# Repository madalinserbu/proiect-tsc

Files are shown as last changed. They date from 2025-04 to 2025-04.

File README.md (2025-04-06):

# OpenBook
Proiect TSC - Serbu Ovidiu Madalin

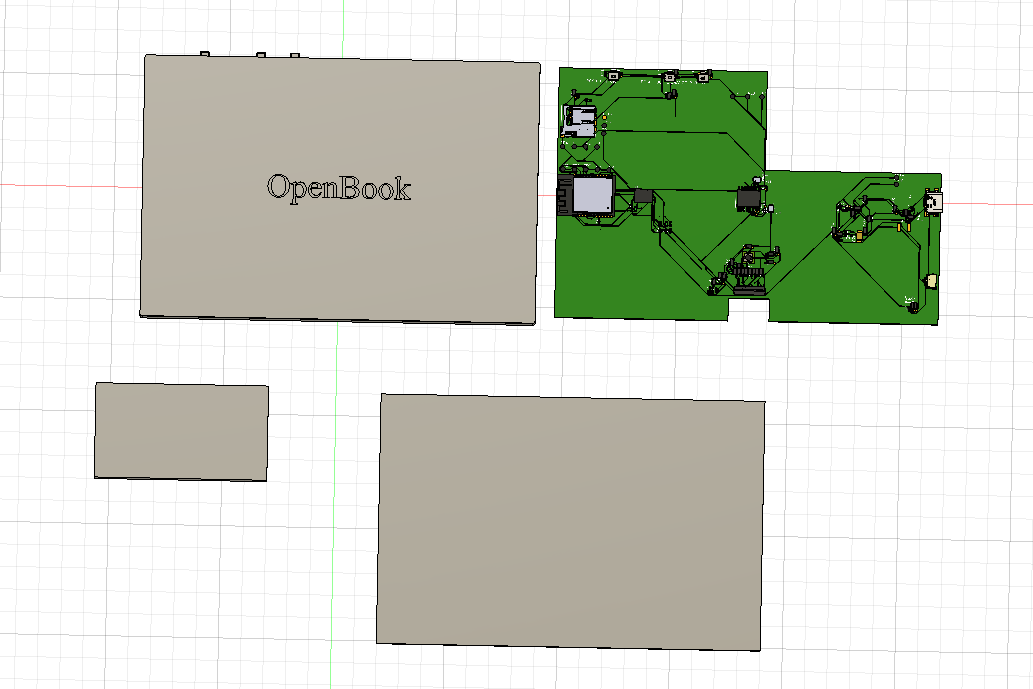
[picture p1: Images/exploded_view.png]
Exploded View


## Block Diagram

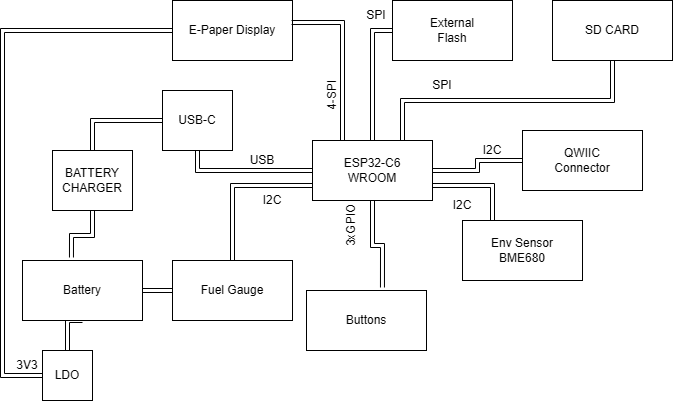
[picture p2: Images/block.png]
block


## Components

- **Microcontroller:** ESP32-C6 with integrated Wi-Fi 6 and Bluetooth 5 — responsible for core processing, communication, and power management.
- **Display:** 800×480 resolution e-Paper (e-Ink) display interfaced via SPI — ideal for low-power, high-visibility content rendering.
- **Sensors:** BME688 environmental sensor (temperature, humidity, pressure, air quality) connected through I2C.
- **Power Supply:** 2500mAh LiPo battery with USB-C charging and integrated fuel gauge for real-time battery monitoring.
- **Storage:** MicroSD card slot for storing e-books and other resources, communicating via SPI.
- **Real-Time Clock:** DS3231 RTC module with battery backup for accurate timekeeping even during power loss.
- **User Inputs:** 3 buttons (connected via GPIO) for navigation and control.
- **Expansion Options:** QWIIC/Stemma QT connector for easy integration of additional sensors or modules.

## Bill Of Materials

| name 	| value 	| description 	| quantity 	| link 	| datasheet 	|
|:---:	|:---:	|---	|:---:	|:---:	|---	|
| LED1 	| - 	| LED 	| 1 	| [link](https://www.niden.ro/led-uri-smd/4560-led-smd-0603-alb-rece.html) 	| [link](https://www.mouser.com/datasheet/2/423/LSM0603472V_(1)-1379786.pdf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)	|
| C18 	| 0.1uF/50V 	| CAPACITOR, European symbol 	| 1 	| [link](https://ro.mouser.com/ProductDetail/KEMET/C0402C104K4RAC7411?qs=GedzDrHbfJPMv36lRRfk4g%3D%3D) 	| [link](https://ro.mouser.com/datasheet/2/447/KEM_C1002_X7R_SMD-3316098.pdf) 	|
| R5 	| 0.47 	| RESISTOR, European symbol 	| 1 	| [link](https://ro.mouser.com/ProductDetail/ROHM-Semiconductor/SFR01MZPJ471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) 	| [link](https://fscdn.rohm.com/en/products/databook/datasheet/passive/resistor/chip_resistor/sfr-e.pdf) 	|
| R1 	| 100K 	| RESISTOR, European symbol 	| 1 	| [link](https://ro.mouser.com/ProductDetail/Bourns/CR0402-FX-1003GLF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) 	| [link](https://ro.mouser.com/datasheet/2/54/cr-1858361.pdf) 	|
| C1, C5, C21, C22, C23, C25, C26, C27 	| 100nF 	| CAPACITOR, European symbol 	| 8 	| [link](https://ro.mouser.com/ProductDetail/KEMET/C0402C104K4RAC7411?qs=GedzDrHbfJPMv36lRRfk4g%3D%3D) 	| [link](https://ro.mouser.com/datasheet/2/447/KEM_C1002_X7R_SMD-3316098.pdf) 	|
| C2 	| 100uF 	| POLARIZED CAPACITOR, European symbol 	| 1 	| [link](https://ro.mouser.com/ProductDetail/KEMET/T491B107M006AT?qs=U312oeP%2FpiHOgyk6KO2m0g%3D%3D) 	| [link](https://ro.mouser.com/datasheet/2/447/KEM_T2005_T491-3316937.pdf) 	|
| R18 	| 10K 	| RESISTOR, European symbol 	| 1 	| [link](https://ro.mouser.com/ProductDetail/Vishay-Dale/CRCW040210K0FKEDC?qs=E3Y5ESvWgWPiNLcGzwCGPg%3D%3D) 	| [link](https://www.vishay.com/docs/28773/crcwce3.pdf) 	|
| R6, R10, R11, R12, R13, R14, R15, R16, R19, R20, R21, R22, R23, R24, R25 	| 10k 	| RESISTOR, European symbol 	| 15 	| [link](https://ro.mouser.com/ProductDetail/Vishay-Dale/CRCW040210K0FKEDC?qs=E3Y5ESvWgWPiNLcGzwCGPg%3D%3D) 	| [link](https://www.vishay.com/docs/28773/crcwce3.pdf) 	|
| C7 	| 10uF 	| CAPACITOR, European symbol 	| 1 	| [link](https://ro.mouser.com/ProductDetail/KEMET/C0402C106M7PAC7867?qs=kZJHmUDErizJnkDIcqVWRQ%3D%3D) 	| [link](https://ro.mouser.com/datasheet/2/447/KEM_C1006_X5R_SMD-3316465.pdf) 	|
| J1 	| - 	| Micro SD Card Socket, Push-Push Type, Top Mount, SMT, H=1.83mm, 10u 	| 1 	| [link](https://www.digikey.ro/en/products/detail/attend-technology/112A-TAAR-R03/17633923) 	| [link](https://www.attend.com.tw/data/download/file/112A-TAAR-R03_Spec.pdf) 	|
| R17 	| 15 	| RESISTOR, European symbol 	| 1 	| [link](https://www.soselectronic.com/ro-ro/products/yageo/r0402-5-15-r-rc0402jr-0715rl-1-81614) 	| [link](https://cdn.soselectronic.com/productdata/4b/af/65353ac1/r0402-1-1-5-k-rc0402fr-071k5l-1.pdf) 	|
| C24 	| 1uF 	| CAPACITOR, European symbol 	| 1 	| [link](https://ro.mouser.com/ProductDetail/KEMET/C0402C105Z9VACTU?qs=gt1LBUVyoHlQieoJt4iw1w%3D%3D) 	| [link](https://ro.mouser.com/datasheet/2/447/KEM_C1005_Y5V_SMD-3316374.pdf) 	|
| C11, C12, C13, C14, C15, C16, C17, C19, C20 	| 1uF/50V 	| CAPACITOR, European symbol 	| 9 	| [link](https://ro.mouser.com/ProductDetail/KEMET/C0402C105Z9VACTU?qs=gt1LBUVyoHlQieoJt4iw1w%3D%3D) 	| [link](https://ro.mouser.com/datasheet/2/447/KEM_C1005_Y5V_SMD-3316374.pdf) 	|
| R7 	| 2.2 	| RESISTOR, European symbol 	| 1 	| [link](https://ro.mouser.com/ProductDetail/Panasonic/ERJ-PA2J2R2X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) 	| [link](https://industrial.panasonic.com/cdbs/www-data/pdf/RDO0000/AOA0000C331.pdf) 	|
| R8 	| 200 	| RESISTOR, European symbol 	| 1 	| [link](https://ro.mouser.com/ProductDetail/Vishay-Thin-Film/PNM0402E2000BSTS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) 	| [link](https://www.vishay.com/docs/60057/pnm.pdf) 	|
| Q1, Q3 	| 20V/4.2A/52mO/1.4W 	| P-channel MOSFETs 	| 2 	| [link](https://www.digikey.ro/en/products/detail/vishay-siliconix/SI1308EDL-T1-GE3/4876435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) 	| [link](https://www.vishay.com/docs/63399/si1308edl.pdf) 	|
| R9 	| 2k 	| RESISTOR, European symbol 	| 1 	| [link](https://ro.mouser.com/ProductDetail/Vishay-Dale/CRCW04022K00FKEE?qs=raETa%252B32nO8lGcRW9MjUBA%3D%3D) 	| [link](https://www.vishay.com/docs/20035/dcrcwe3.pdf) 	|
| C6, C9, C10 	| 4.7uF 	| CAPACITOR, European symbol 	| 3 	| [link](https://ro.mouser.com/ProductDetail/KEMET/C0402C475K8PACTU?qs=ulEaXIWI0c9ebKRT3r3htg%3D%3D) 	| [link](https://ro.mouser.com/datasheet/2/447/KEM_C1006_X5R_SMD-3316465.pdf) 	|
| C3, C4 	| 4.7uF 	| CAPACITOR, European symbol 	| 2 	| [link](https://ro.mouser.com/ProductDetail/KEMET/C0402C475K8PACTU?qs=ulEaXIWI0c9ebKRT3r3htg%3D%3D) 	| [link](https://ro.mouser.com/datasheet/2/447/KEM_C1006_X5R_SMD-3316465.pdf) 	|
| C8 	| 4.7uF/25V 	| CAPACITOR, European symbol 	| 1 	| [link](https://ro.mouser.com/ProductDetail/KEMET/C0402C475K8PACTU?qs=ulEaXIWI0c9ebKRT3r3htg%3D%3D) 	| [link](https://ro.mouser.com/ProductDetail/KEMET/C0402C475K8PACTU?qs=ulEaXIWI0c9ebKRT3r3htg%3D%3D) 	|
| D3 	| 4.7uF/25V 	| ON SEMICONDUCTOR - MBR0530 - DIODE, SCHOTTKY, 0.5A, 30V, SOD-123 	| 1 	| [link](https://www.snapeda.com/parts/MBR0530/Onsemi/view-part/?ref=eda) 	| [link](https://www.snapeda.com/parts/MBR0530/ON%20Semiconductor/datasheet/) 	|
| R3, R4 	| 5k1 	| RESISTOR, European symbol 	| 2 	| [link](https://www.gme.cz/v/1484336/yageo-r0402-5k1-006w-1-smd-rezistor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) 	| [link](https://img.gme.cz/files/eshop_data/eshop_data/7/984-017/dsh.984-017.1.pdf) 	|
| L1 	| 68uH 	| coil 	| 1 	| [link](https://ro.mouser.com/ProductDetail/Wurth-Elektronik/744043680?qs=PGXP4M47uW6VkZq%252BkzjrHA%3D%3D) 	| [link](https://www.we-online.com/components/products/datasheet/744043680.pdf) 	|
| IC2 	| - 	| Voltage Detector with Adjustable Delay 	| 1 	| [link](https://ro.mouser.com/ProductDetail/ROHM-Semiconductor/BD5229G-TR?qs=4kLU8WoGk0vvnhrrYwdszw%3D%3D) 	| [link](https://fscdn.rohm.com/en/products/databook/datasheet/ic/power/voltage_detector/bd52xxg-e.pdf) 	|
| BOOT_BUTTON, CHANGE_BUTTON, RESET_BUTTON 	| - 	| Button 	| 3 	| [link](https://ro.mouser.com/ProductDetail/CK/PTS841-GK-SMTR-LFS?qs=d0WKAl%252BL4KbAtAqJT9yhkg%3D%3D) 	| [link](https://www.ckswitches.com/media/2805/pts841.pdf) 	|
| C28 	| - 	| Cap 0.011F 3.3V 1210 Flat 	| 1 	| [link](https://www.snapeda.com/parts/CPH3225A/Seiko+Instruments/view-part/?ref=eda) 	| [link](https://www.snapeda.com/parts/CPH3225A/Seiko%20Instruments/datasheet/) 	|
| U5 	| - 	| Real Time Clock Serial 16-Pin SOIC W T/R 	| 1 	| [link](https://www.snapeda.com/parts/DS3231SN%23/Analog+Devices/view-part/?ref=eda) 	| [link](https://www.snapeda.com/parts/DS3231SN%23/Analog%20Devices/datasheet/) 	|
| U2 	| - 	| ESP32 	| 1 	| [link](https://www.snapeda.com/parts/ESP32-C6-WROOM-1-N8/Espressif+Systems/view-part/?ref=eda) 	| [link](https://www.snapeda.com/parts/ESP32-C6-WROOM-1-N8/Espressif%20Systems/datasheet/) 	|
| R2 	| - 	| VARISTOR 	| 1 	| [link](https://www.digikey.ro/en/products/detail/epcos-tdk-electronics/B72580T0110K062/15903564) 	| [link](https://www.tdk-electronics.tdk.com/inf/75/db/CTVS_14/Standard_series.pdf) 	|
| D1, D6 	| - 	| Schottky Barrier Rectifier Diode 	| 2 	| [link](https://eu.mouser.com/ProductDetail/KYOCERA-AVX/SD0805S020S1R0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) 	| [link](https://ro.mouser.com/datasheet/2/40/schottky-3165252.pdf) 	|
| U3 	| - 	| Integrated Environmental Unit 	| 1 	| [link](https://ro.mouser.com/ProductDetail/Bosch-Sensortec/BME680?qs=v271MhAjFHjo0yA%2FC4OnDQ%3D%3D) 	| [link](https://ro.mouser.com/datasheet/2/783/BST_BME680_DS001-1509608.pdf) 	|
| U1 	| - 	| MCP73831T Li-Ion, Li-Pol Controller 	| 1 	| [link](https://eu.mouser.com/ProductDetail/Microchip-Technology/MCP73831T-2ACI-OT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) 	| [link](https://ro.mouser.com/datasheet/2/268/MCP73831_Family_Data_Sheet_DS20001984H-3441711.pdf) 	|
| J3 	| - 	|  (0.50mm) Surface Mount, Right Angle 	| 1 	| [link](https://ro.mouser.com/ProductDetail/Hirose-Connector/FH34SRJ-24S-0.5SH99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.) 	| [link](https://ro.mouser.com/datasheet/2/185/FH34SRJ_24S_0_5SH_99__CL0580_1255_6_99_2DDrawing_0-1615044.pdf) 	|
| U4 	| - 	| 3µA 1-Cell/2-Cell Fuel Gauge with ModelGauge 	| 1 	| [link](https://www.snapeda.com/parts/MAX17048G+T10/Analog+Devices/view-part/?ref=eda) 	| [link](https://www.snapeda.com/parts/MAX17048G+T10/Analog%20Devices/datasheet/) 	|
| D4, D5 	| - 	| DIODE, SCHOTTKY, 0.5A, 30V, SOD-123 	| 2 	| [link](https://www.snapeda.com/parts/MBR0530/Onsemi/view-part/?ref=eda) 	| [link](https://www.snapeda.com/parts/MBR0530/ON%20Semiconductor/datasheet/) 	|
| D7, D8, D9, D10, D11, D12 	| - 	| Ipp Tvs Diode 	| 6 	| [link](https://www.snapeda.com/parts/PGB1010603MR/Littelfuse/view-part/?ref=eda) 	| [link](https://www.snapeda.com/parts/PGB1010603MR/Littelfuse%20Inc./datasheet/) 	|
| J4 	| - 	| SparkFun I2C Standard Qwiic Connector 	| 1 	| [link](https://www.sparkfun.com/qwiic-jst-connector-smd-4-pin-horizontal.html) 	| [link](https://cdn.sparkfun.com/assets/parts/1/2/2/8/9/Qwiic_Connector_Datasheet.pdf) 	|
| J2 	| - 	| CONN USB 2.0 TYPE-C R/A SMT 	| 1 	| [link](https://ro.mouser.com/ProductDetail/GCT/USB4110-GF-A?qs=KUoIvG%2F9IlYiZvIXQjyJeA%3D%3D) 	| [link](https://ro.mouser.com/datasheet/2/837/GCT_USB4110_Product_Drawing___20k_cycles-3455479.pdf) 	|
| Q2 	| - 	| MOSFET N-Ch 30V 1.5A 	| 1 	| [link](https://www.snapeda.com/parts/SI1308EDL-T1-GE3/Vishay+Siliconix/view-part/?ref=eda) 	| [link](https://www.snapeda.com/parts/SI1308EDL-T1-GE3/Vishay%20Siliconix/datasheet/) 	|
| D2 	| - 	| Low Cap. ESD Protection Auto SOT-23-6 	| 1 	| [link](https://www.snapeda.com/parts/USBLC6-2SC6Y/STMicroelectronics/view-part/?ref=eda) 	| [link](https://www.snapeda.com/parts/USBLC6-2SC6Y/STMicroelectronics/datasheet/) 	|
| U6 	| - 	| FLASH - NOR Memory IC 512Mb 	| 1 	| [link](https://www.snapeda.com/parts/W25Q512JVEIQ/Winbond+Electronics/view-part/?ref=eda) 	| [link](https://www.snapeda.com/parts/W25Q512JVEIQ/Winbond%20Electronics/datasheet/) 	|
| IC1 	| - 	| LDO Voltage Regulator 	| 1 	| [link](https://ro.mouser.com/ProductDetail/Torex-Semiconductor/XC6220A331MR-G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) 	| [link](https://ro.mouser.com/datasheet/2/760/xc6220-3371556.pdf) 	|

## ESP32-C6 Pins

| Connection | Pin | Description |
|---|---|---|
| **RESET** | EN | Reset button for initiating a reset sequence |
| **INT_RTC** | IO0 | Interrupt signal for the RTC |
| **32KHZ** | IO1 | Input for 32kHz clock signal |
| **MISO** | IO2 | Master In Slave Out for communication between the microcontroller, Flash, SD Card, and display |
| **EPD_BUSY** | IO3 | Signal indicating if the display is busy |
| **SS_SD** | IO4 | Chip select for the SD card |
| **EPD_DC** | IO5 | Display data/command control pin |
| **SCK** | IO6 | SPI clock for synchronizing data transfers |
| **MOSI** | IO7 | Master Out Slave In for data transmission between the microcontroller, Flash, SD card, and display |
| **3V3** | IO8 | 3.3V power supply |
| **IO/BOOT** | IO9 | Boot button to trigger boot process |
| **EPD_CS** | IO10 | Chip select for the display |
| **FLASH_CS** | IO11 | Chip select for the Flash memory |
| **USB_D-** | IO12 | USB data negative for communication |
| **USB_D+** | IO13 | USB data positive for communication |
| **IO/CHANGE** | IO15 | Button to trigger a change action |
| **TX (UART)** | TXD0 / GPIO16  | Serial transmitter for UART communication |
| **RX (UART)** | RXD0 / GPIO17  | Serial receiver for UART communication |
| **RTC_RST** | IO18 | External reset for the RTC module |
| **I2C_PW** | IO19 | Power control signal for I2C devices |
| **EPD_3V3_C** | IO20 | 3.3V power supply for the display |
| **SDA (I2C)** | IO21 | Data line for I2C communication (e.g., RTC, BME688, Battery Gauge) |
| **SCL (I2C)** | IO22 | Clock line for I2C synchronization |
| **EPD_RST** | IO23 | Reset signal for the display |
| **3V3** | 3V3 | 3.3V power line |
| **GND** | GND | Ground connection |

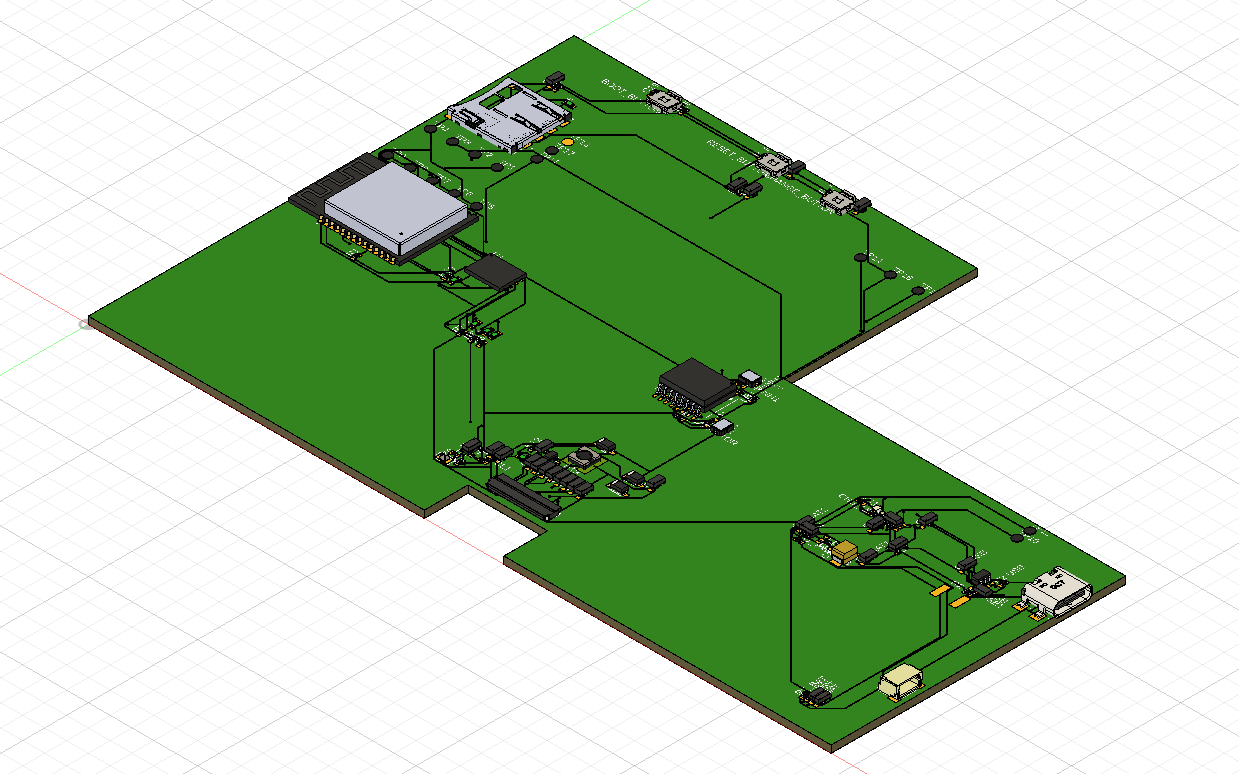
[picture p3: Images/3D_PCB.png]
3DPCB


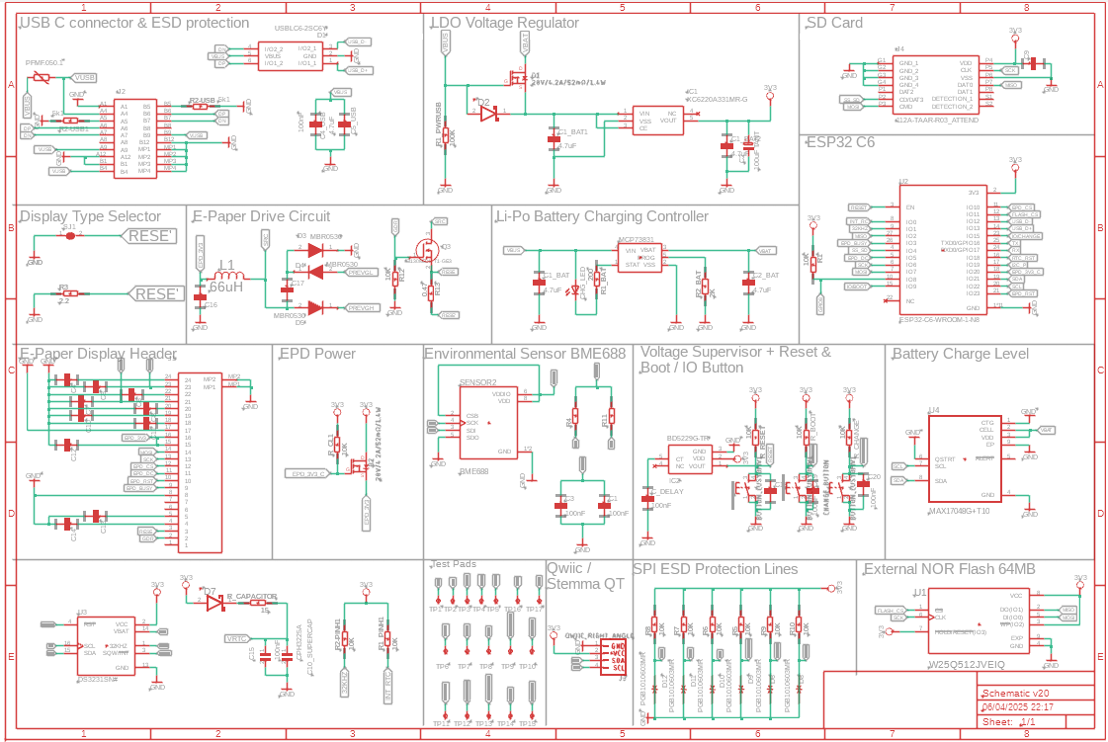
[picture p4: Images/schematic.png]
schematic


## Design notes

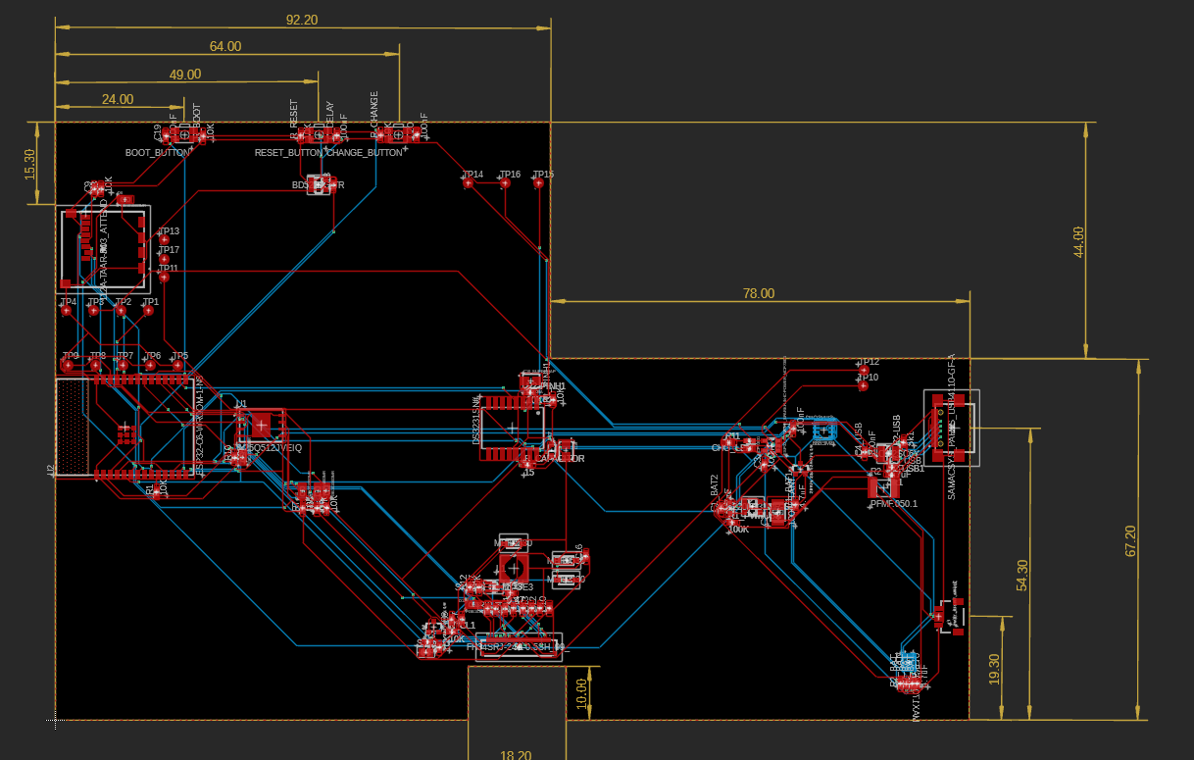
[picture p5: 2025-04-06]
Images/2D_PCB.png

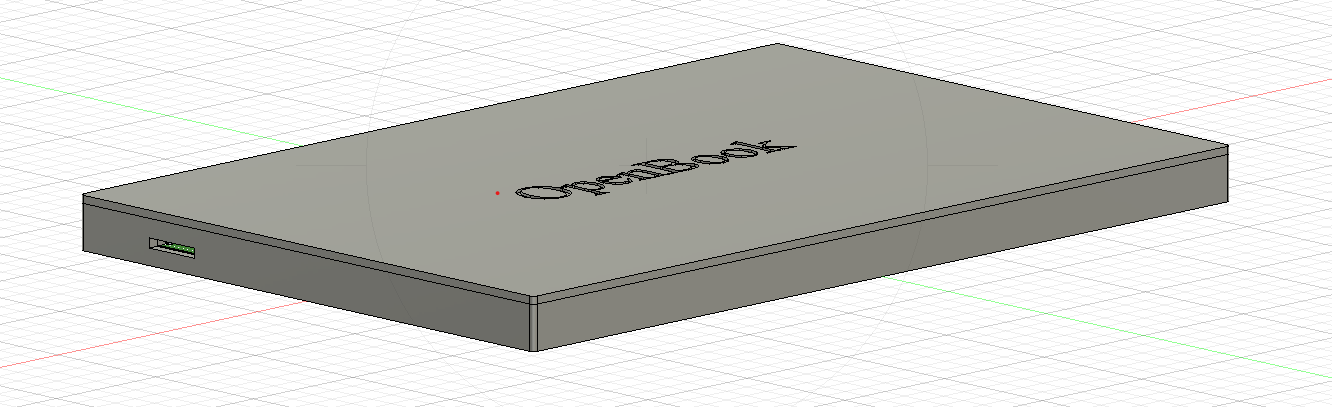
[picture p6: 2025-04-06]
Images/complete_device.png

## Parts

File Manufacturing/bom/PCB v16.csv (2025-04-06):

Qty | Value | Device | Package | Parts | Description | ARROW_PART_NUMBER | ARROW_PRICE-STOCK | AVAILABILITY | CENTROID_NOT_SPECIFIED | CHECK_PRICES | COPYRIGHT | DATASHEET | DESCRIPTION | DIGIKEY_DESCRIPTION | DIGIKEY_PART_NUMBER | HEIGHT | LEAD_FREE | MANUFACTURER_NAME | MANUFACTURER_PART_NUMBER | MF | MFR_NAME | MOUSER_PART_NUMBER | MOUSER_PRICE-STOCK | MOUSER_TESTING_PART_NUMBER | MOUSER_TESTING_PRICE-STOCK | MP | MPN | PACKAGE | POPULARITY | PREFIX | PRICE | PROD_ID | PURCHASE-URL | ROHS | SNAPEDA_LINK | SPICEMODEL | SPICEPREFIX | TEMPERATURE_RANGE_HIGH | TEMPERATURE_RANGE_LOW | TP_SIGNAL_NAME | VALUE
1 |  | ADAFRUIT_LEDCHIP-LED0603 | ADAFRUIT_CHIP-LED0603 | CHG_LED | LED
14 |  | ESP32_WROVER_EAGLE-LTSPICE_CC0402 | ESP32_WROVER_EAGLE-LTSPICE_C0402 | C4, C5, C6, C7, C8, C9, C10, C11, C12, C13, C14, C16, C17, C18 | CAPACITOR, European symbol |  |  |  |  |  |  |  |  |  |  |  |  |  |  |  |  |  |  |  |  |  |  |  |  |  |  |  |  |  |  | NONE | C
2 |  | ESP32_WROVER_EAGLE-LTSPICE_RR0402 | ESP32_WROVER_EAGLE-LTSPICE_R0402 | R4, R11 | RESISTOR, European symbol |  |  |  |  |  |  |  |  |  |  |  |  |  |  |  |  |  |  |  |  |  |  |  |  |  |  |  |  |  |  | NONE | R
1 |  | SJ | SJ | SJ1 | SMD solder JUMPER |  |  |  |  |  |  |  |  |  |  |  |  |  |  |  |  |  |  |  |  |  |  |  | 3
1 | 0.47 | ESP32_WROVER_EAGLE-LTSPICE_RR0402 | ESP32_WROVER_EAGLE-LTSPICE_R0402 | R13 | RESISTOR, European symbol |  |  |  |  |  |  |  |  |  |  |  |  |  |  |  |  |  |  |  |  |  |  |  |  |  |  |  |  |  |  | NONE | R
1 | 100K | ESP32_WROVER_EAGLE-LTSPICE_RR0402 | ESP32_WROVER_EAGLE-LTSPICE_R0402 | R1_PWRUSB | RESISTOR, European symbol |  |  |  |  |  |  |  |  |  |  |  |  |  |  |  |  |  |  |  |  |  |  |  |  |  |  |  |  |  |  | NONE | R
1 | 100nF | CPH3225A | CAPCP3225X100N | C15 | Cap 0.011F 3.3V 1210 Flat Check availability |  |  | Not in stock |  | https://www.snapeda.com/parts/CPH3225A/Seiko+Instruments/view-part/?ref=eda |  |  | 11 mF (EDLC) Supercapacitor 3.3 V 1210 (3225 Metric) - - |  |  |  |  |  |  | Seiko Instruments |  |  |  |  |  | CPH3225A |  | 1210 Seiko |  |  | None |  | https://www.snapeda.com/api/url_track_click_mouser/?unipart_id=562593&manufacturer=Seiko Instruments&part_name=CPH3225A&search_term=None |  | https://www.snapeda.com/parts/CPH3225A/Seiko+Instruments/view-part/?ref=snap
1 | 100nF | EAGLE-LTSPICE_CC0402 | ESP32_WROVER_EAGLE-LTSPICE_C0402 | C19 | CAPACITOR, European symbol |  |  |  |  |  |  |  |  |  |  |  |  |  |  |  |  |  |  |  |  |  |  |  |  |  |  |  |  |  |  | NONE | C
5 | 100nF | ESP32_WROVER_EAGLE-LTSPICE_CC0402 | ESP32_WROVER_EAGLE-LTSPICE_C0402 | C1, C3, C4_USB, C20, C_DELAY | CAPACITOR, European symbol |  |  |  |  |  |  |  |  |  |  |  |  |  |  |  |  |  |  |  |  |  |  |  |  |  |  |  |  |  |  | NONE | C
1 | 100uF TANT | RCL_CPOL-EUCT3528 | RCL_CT3528 | C2 | POLARIZED CAPACITOR, European symbol |  |  |  |  |  |  |  |  |  |  |  |  |  |  |  |  |  |  |  |  |  |  |  | 0 |  |  |  |  |  |  |  | C
14 | 10K | ESP32_WROVER_EAGLE-LTSPICE_RR0402 | ESP32_WROVER_EAGLE-LTSPICE_R0402 | R1, R1_PINH1, R2-PINH1, R5, R6, R7, R8, R9, R10, R12, R_BOOT, R_CHANGE, R_CL1, R_RESET | RESISTOR, European symbol |  |  |  |  |  |  |  |  |  |  |  |  |  |  |  |  |  |  |  |  |  |  |  |  |  |  |  |  |  |  | NONE | R
1 | 112A-TAAR-R03_ATTEND | 112A-TAAR-R03_ATTEND | 112ATAARR03ATTEND | J4 | Micro SD Card Socket, Push-Push Type, Top Mount, SMT, H=1.83mm, 10u |  |  |  |  |  |  |  | Micro SD Card Socket | Push-Push Type | Top Mount | SMT | H=1.83mm | 10u |  |  | 1.9mm |  | ATTEND | 112A-TAAR-R03 ATTEND
1 | 15 | ESP32_WROVER_EAGLE-LTSPICE_RR0402 | ESP32_WROVER_EAGLE-LTSPICE_R0402 | R_CAPACITOR | RESISTOR, European symbol |  |  |  |  |  |  |  |  |  |  |  |  |  |  |  |  |  |  |  |  |  |  |  |  |  |  |  |  |  |  | NONE | R
1 | 2.2 | ESP32_WROVER_EAGLE-LTSPICE_RR0402 | ESP32_WROVER_EAGLE-LTSPICE_R0402 | R3 | RESISTOR, European symbol |  |  |  |  |  |  |  |  |  |  |  |  |  |  |  |  |  |  |  |  |  |  |  |  |  |  |  |  |  |  | NONE | R
1 | 200 | ESP32_WROVER_EAGLE-LTSPICE_RR0402 | ESP32_WROVER_EAGLE-LTSPICE_R0402 | R1_BAT | RESISTOR, European symbol |  |  |  |  |  |  |  |  |  |  |  |  |  |  |  |  |  |  |  |  |  |  |  |  |  |  |  |  |  |  | NONE | R
2 | 20V/4.2A/52mO/1.4W | ESP32_WROVER_SPARKFUN-DISCRETESEMI_MOSFET_PCH-DMG2305UX-7 | ESP32_WROVER_SPARKFUN-DISCRETESEMI_SOT23-3 | Q1, Q2 | P-channel MOSFETs |  |  |  |  |  |  |  |  |  |  |  |  |  |  |  |  |  |  |  |  |  |  |  |  |  |  | TRAN-14388 |  |  |  |  |  |  |  |  | 20V/4.2A/52mO/1.4W
1 | 2K | ESP32_WROVER_EAGLE-LTSPICE_RR0402 | ESP32_WROVER_EAGLE-LTSPICE_R0402 | R2_BAT | RESISTOR, European symbol |  |  |  |  |  |  |  |  |  |  |  |  |  |  |  |  |  |  |  |  |  |  |  |  |  |  |  |  |  |  | NONE | R
5 | 4.7uF | ESP32_WROVER_EAGLE-LTSPICE_CC0402 | ESP32_WROVER_EAGLE-LTSPICE_C0402 | C1_BAT, C1_BAT1, C1_BAT2, C2_BAT, C5_USB | CAPACITOR, European symbol |  |  |  |  |  |  |  |  |  |  |  |  |  |  |  |  |  |  |  |  |  |  |  |  |  |  |  |  |  |  | NONE | C
2 | 5k1 | ESP32_WROVER_EAGLE-LTSPICE_RR0402 | ESP32_WROVER_EAGLE-LTSPICE_R0402 | R2-USB, R2-USB1 | RESISTOR, European symbol |  |  |  |  |  |  |  |  |  |  |  |  |  |  |  |  |  |  |  |  |  |  |  |  |  |  |  |  |  |  | NONE | R
1 | 66uH | 744043680IND_4828-WE-TPC_WRE | IND_4828-WE-TPC_WRE | L1 |  |  |  |  |  |  | Copyright (C) 2024 Ultra Librarian. All rights reserved. |  |  |  |  |  |  |  | 744043680 |  | Wurth Electronics
1 | BD5229G-TR | BD5229G-TR | SOT95P280X125-5N | IC2 | Voltage Detector with Adjustable Delay Time: CMOS processes are utilized to develop high precision, low current consumption CMOS reset ICs that allow arbitrary setting of the delay time. The extensive lineup includes both Nch Open Drain and CMOS output types in a wide range of detection voltages (from 2.3V to 6.0V, in 0.1V steps), enabling selection of the ideal solution based on customer requirements. In addition, the entire series is of course both lead-free and RoHS-compliant. |  |  |  |  |  |  |  | Voltage Detector with Adjustable Delay Time: CMOS processes are utilized to develop high precision | low current consumption CMOS reset ICs that allow arbitrary setting of the delay time. The extensive lineup includes both Nch Open Drain and CMOS output types in a wide range of detection voltages (from 2.3V to 6.0V | in 0.1V steps) | enabling selection of the ideal solution based on customer requirements. In addition | the entire series is of course both lead-free and RoHS-compliant. |  |  | 1.25mm |  | ROHM Semiconductor | BD5229G-TR |  |  | 755-BD5229G-TR | https://www.mouser.co.uk/ProductDetail/ROHM-Semiconductor/BD5229G-TR?qs=4kLU8WoGk0vvnhrrYwdszw%3D%3D
1 | BME688 | ESP32_WROVER_BME680_BME680 | ESP32_WROVER_BME680_PSON80P300X300X100-8N | SENSOR2 | Integrated Environmental Unit |  |  | Unavailable |  |  |  |  | Integrated Environmental Unit |  |  |  |  |  |  | Bosch Sensortec |  |  |  |  |  | BME680 |  | LGA-8 Bosch Tools |  |  | None
3 | BUTTON_CUSYOMV1 | BUTTON_CUSYOMV1 | MYBUTTON | BOOT_BUTTON, CHANGE_BUTTON, RESET_BUTTON
1 | CPH3225A | CPH3225A | CAPCP3225X100N | C10_SUPERCAP | Cap 0.011F 3.3V 1210 Flat Check availability |  |  | Not in stock |  | https://www.snapeda.com/parts/CPH3225A/Seiko+Instruments/view-part/?ref=eda |  |  | 11 mF (EDLC) Supercapacitor 3.3 V 1210 (3225 Metric) - - |  |  |  |  |  |  | Seiko Instruments |  |  |  |  |  | CPH3225A |  | 1210 Seiko |  |  | None |  | https://www.snapeda.com/api/url_track_click_mouser/?unipart_id=562593&manufacturer=Seiko Instruments&part_name=CPH3225A&search_term=None |  | https://www.snapeda.com/parts/CPH3225A/Seiko+Instruments/view-part/?ref=snap
1 | DS3231SN# | DS3231SN# | SOIC127P1032X265-16N | U3 | Real Time Clock Serial 16-Pin SOIC W T/R Check availability |  |  | In Stock |  | https://www.snapeda.com/parts/DS3231SN%23/Analog+Devices/view-part/?ref=eda |  |  | Extremely Accurate I²C-Integrated RTC/TCXO/Crystal |  |  |  |  |  |  | Analog Devices |  |  |  |  |  | DS3231SN# |  | SOIC-16 Maxim |  |  | None |  | https://www.snapeda.com/api/url_track_click_mouser/?unipart_id=99048&manufacturer=Analog Devices&part_name=DS3231SN#&search_term=None |  | https://www.snapeda.com/parts/DS3231SN%23/Analog+Devices/view-part/?ref=snap
1 | ESP32-C6-WROOM-1-N8 | ESP32-C6-WROOM-1-N8 | XCVR_ESP32-C6-WROOM-1-N8 | U2 | Check availability |  |  | In Stock |  | https://www.snapeda.com/parts/ESP32-C6-WROOM-1-N8/Espressif+Systems/view-part/?ref=eda |  |  | Multiprotocol Modules ESP32-C6 module | Wi-Fi 6 in 2.4 GHz band | Bluetooth 5 | Zigbee 3.0 and Thread. ESP34-WROOM Compatible - ENGINEERING SAMPLE |  |  |  |  |  |  | Espressif Systems |  |  |  |  |  | ESP32-C6-WROOM-1-N8 |  | None |  |  | None |  |  |  | https://www.snapeda.com/parts/ESP32-C6-WROOM-1-N8/Espressif+Systems/view-part/?ref=snap
1 | ESP32_WROVER_AVX---SD0805S020S1R0_AVX_SD0805S020S1R0_0_0AVX_SD0805S020S1R0_0_0 | ESP32_WROVER_AVX---SD0805S020S1R0_AVX_SD0805S020S1R0_0_0AVX_SD0805S020S1R0_0_0 | ESP32_WROVER_AVX---SD0805S020S1R0_AVX_SD0805S020S1R0_0 | D7 | Schottky Barrier Rectifier Diode |  |  |  | No |  |  | http://datasheets.avx.com/schottky.pdf |  | DIODE SCHOTTKY 20V 1A 0805 | 478-7800-1-ND |  | yes |  |  | AVX |  | 581-SD0805S020S1R0 |  |  |  |  |  | 0805 (2012 metric) |  | D |  |  |  | yes |  |  |  | +125°C | -55°C
1 | ESP32_WROVER_SPARKFUN-IC-POWER_MCP73831 | ESP32_WROVER_SPARKFUN-IC-POWER_MCP73831 | ESP32_WROVER_SPARKFUN-IC-POWER_SOT23-5 | MCP73831 | MCP73831T Li-Ion, Li-Pol Controller |  |  |  |  |  |  |  |  |  |  |  |  |  |  |  |  |  |  |  |  |  |  |  |  |  |  | IC-09995
1 | FH34SRJ-24S-0.5SH_99_ | FH34SRJ-24S-0.5SH_99_ | FH34SRJ24S05SH99 | J1 | (0.50mm) Surface Mount, Right Angle |  |  |  |  |  |  |  | 24 Position FFC | FPC Connector Contacts | (0.50mm) Surface Mount | Right Angle |  |  | 1.1mm |  | Hirose | FH34SRJ-24S-0.5SH(99) |  |  | 798-FH34SRJ24S05SH99 | https://www.mouser.co.uk/ProductDetail/Hirose-Connector/FH34SRJ-24S-0.5SH99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
1 | MAX17048G+T10 | MAX17048G+T10 | SON50P200X200X80-9N | U4 | Check availability |  |  | In Stock |  | https://www.snapeda.com/parts/MAX17048G+T10/Analog+Devices/view-part/?ref=eda |  |  | 3µA 1-Cell/2-Cell Fuel Gauge with ModelGauge |  |  |  |  |  |  | Analog Devices |  |  |  |  |  | MAX17048G+T10 |  | TDFN-8 Maxim |  |  | None |  | https://www.snapeda.com/api/url_track_click_mouser/?unipart_id=329239&manufacturer=Analog Devices&part_name=MAX17048G+T10&search_term=None |  | https://www.snapeda.com/parts/MAX17048G+T10/Analog+Devices/view-part/?ref=snap
3 | MBR0530 | MBR0530 | SOD3716X135N | D3, D4, D5 | ON SEMICONDUCTOR - MBR0530 - DIODE, SCHOTTKY, 0.5A, 30V, SOD-123 |  |  | In Stock |  | https://www.snapeda.com/parts/MBR0530/Onsemi/view-part/?ref=eda |  |  | Diode Schottky 30 V 500mA Surface Mount SOD-123 |  |  |  |  |  |  | ON Semiconductor |  |  |  |  |  | MBR0530 |  | SOD-123-2 ON Semiconductor |  |  | None |  | https://www.snapeda.com/api/url_track_click_mouser/?unipart_id=179458&manufacturer=ON Semiconductor&part_name=MBR0530&search_term=None |  | https://www.snapeda.com/parts/MBR0530/Onsemi/view-part/?ref=snap
1 | PFMF.050.1 | ESP32C6_VARISTORCN1812 | ESP32C6_VARISTOR_CT/CN1812 | R2 | VARISTOR |  |  |  |  |  |  |  |  |  |  |  |  |  |  |  |  |  |  |  |  |  |  |  | 0
6 | PGB1010603MR | PGB1010603MR | DIOC1608X36N | D6, D8, D9, D10, D11, D12 | Check availability |  |  | In Stock |  | https://www.snapeda.com/parts/PGB1010603MR/Littelfuse/view-part/?ref=eda |  |  | 150V (Typ) Clamp - Ipp Tvs Diode Surface Mount 0603 (1608 Metric) |  |  |  |  |  |  | Littelfuse Inc. |  |  |  |  |  | PGB1010603MR |  | 0603 Littelfuse Inc. |  |  | None |  | https://www.snapeda.com/api/url_track_click_mouser/?unipart_id=5659453&manufacturer=Littelfuse Inc.&part_name=PGB1010603MR&search_term=None |  | https://www.snapeda.com/parts/PGB1010603MR/Littelfuse/view-part/?ref=snap
1 | QWIIC_RIGHT_ANGLE | QWIIC_CONNECTORJS-1MM | JST04_1MM_RA | J3 | SparkFun I2C Standard Qwiic Connector |  |  |  |  |  |  |  |  |  |  |  |  |  |  |  |  |  |  |  |  |  |  |  |  |  |  | CONN-13694 |  |  |  |  |  |  |  |  | QWIIC_RIGHT_ANGLE
1 | SAMACSYS_PARTS_USB4110-GF-A | SAMACSYS_PARTS_USB4110-GF-A | SAMACSYS_PARTS_USB4110GFA | J2 | CONN USB 2.0 TYPE-C R/A SMT |  |  |  |  |  |  |  | CONN USB 2.0 TYPE-C R/A SMT |  |  | 3.26mm |  | GCT (GLOBAL CONNECTOR TECHNOLOGY) | USB4110-GF-A |  |  | 640-USB4110-GF-A | https://www.mouser.co.uk/ProductDetail/GCT/USB4110-GF-A?qs=KUoIvG%2F9IlYiZvIXQjyJeA%3D%3D
1 | SD0805S020S1R0 | ESP32_WROVER_AVX---SD0805S020S1R0_AVX_SD0805S020S1R0_0_0AVX_SD0805S020S1R0_0_0 | ESP32_WROVER_AVX---SD0805S020S1R0_AVX_SD0805S020S1R0_0 | D2 | Schottky Barrier Rectifier Diode |  |  |  | No |  |  | http://datasheets.avx.com/schottky.pdf |  | DIODE SCHOTTKY 20V 1A 0805 | 478-7800-1-ND |  | yes |  |  | AVX |  | 581-SD0805S020S1R0 |  |  |  |  |  | 0805 (2012 metric) |  | D |  |  |  | yes |  |  |  | +125°C | -55°C
1 | SI1308EDL-T1-GE3 | SI1308EDL-T1-GE3 | SOT65P210X110-3N | Q3 | MOSFET N-Ch 30V 1.5A TrenchFET SC70 Vishay Si1308EDL-T1-GE3 N-channel MOSFET Transistor, 1.5 A, 30 V, 3-Pin SC-70 |  |  | In Stock |  | https://www.snapeda.com/parts/SI1308EDL-T1-GE3/Vishay+Siliconix/view-part/?ref=eda |  |  | Si1308EDL-T1-GE3 N-channel MOSFET Transistor | 1.5 A | 30 V | 3-Pin SC-70 | Siliconix / Vishay SI1308EDL-T1-GE3 |  |  |  |  |  |  | Vishay Siliconix |  |  |  |  |  | SI1308EDL-T1-GE3 |  | SOT-323 Vishay Semiconductor |  |  | None |  | https://www.snapeda.com/api/url_track_click_mouser/?unipart_id=274603&manufacturer=Vishay Siliconix&part_name=SI1308EDL-T1-GE3&search_term=None |  | https://www.snapeda.com/parts/SI1308EDL-T1-GE3/Vishay+Siliconix/view-part/?ref=snap
17 | TPTP20R | TPTP20R | TP20R | TP1, TP2, TP3, TP4, TP5, TP6, TP7, TP8, TP9, TP10, TP11, TP12, TP13, TP14, TP15, TP16, TP17 | Test pad |  |  |  |  |  |  |  |  |  |  |  |  |  |  |  |  |  |  |  |  |  |  |  | 2
1 | USBLC6-2SC6Y | USBLC6-2SC6Y | SOT95P280X145-6N | D1 | Low Cap. ESD Protection Auto SOT-23-6 STMicroelectronics USBLC6-2SC6Y, Dual Uni-Directional TVS Diode Array, 6-Pin SOT-23 |  |  | In Stock |  | https://www.snapeda.com/parts/USBLC6-2SC6Y/STMicroelectronics/view-part/?ref=eda |  |  | 17V Clamp 5A (8/20µs) Ipp Tvs Diode Surface Mount SOT-23-6 |  |  |  |  |  |  | STMicroelectronics |  |  |  |  |  | USBLC6-2SC6Y |  | SOT-23-6 STMicroelectronics |  |  | None |  |  |  | https://www.snapeda.com/parts/USBLC6-2SC6Y/STMicroelectronics/view-part/?ref=snap
1 | W25Q512JVEIQ | W25Q512JVEIQ | SON127P600X800X80-9N | U1 | Check availability |  |  | In Stock |  | https://www.snapeda.com/parts/W25Q512JVEIQ/Winbond+Electronics/view-part/?ref=eda |  |  | FLASH - NOR Memory IC 512Mb (64M x 8) SPI - Quad I/O 133 MHz 8-WSON (8x6) |  |  |  |  |  |  | Winbond Electronics |  |  |  |  |  | W25Q512JVEIQ |  | Package |  |  | None |  |  |  | https://www.snapeda.com/parts/W25Q512JVEIQ/Winbond+Electronics/view-part/?ref=snap
1 | XC6220A331MR-G | XC6220A331MR-G | SOT95P280X120-5N | IC1 | LDO Voltage Regulators |  |  |  |  |  |  |  | LDO Voltage Regulators |  |  | 1.2mm |  | Torex | XC6220A331MR-G |  |  | 865-XC6220A331MR-G | https://www.mouser.co.uk/ProductDetail/Torex-Semiconductor/XC6220A331MR-G?qs=AsjdqWjXhJ8ZSWznL1J0gg%3D%3D

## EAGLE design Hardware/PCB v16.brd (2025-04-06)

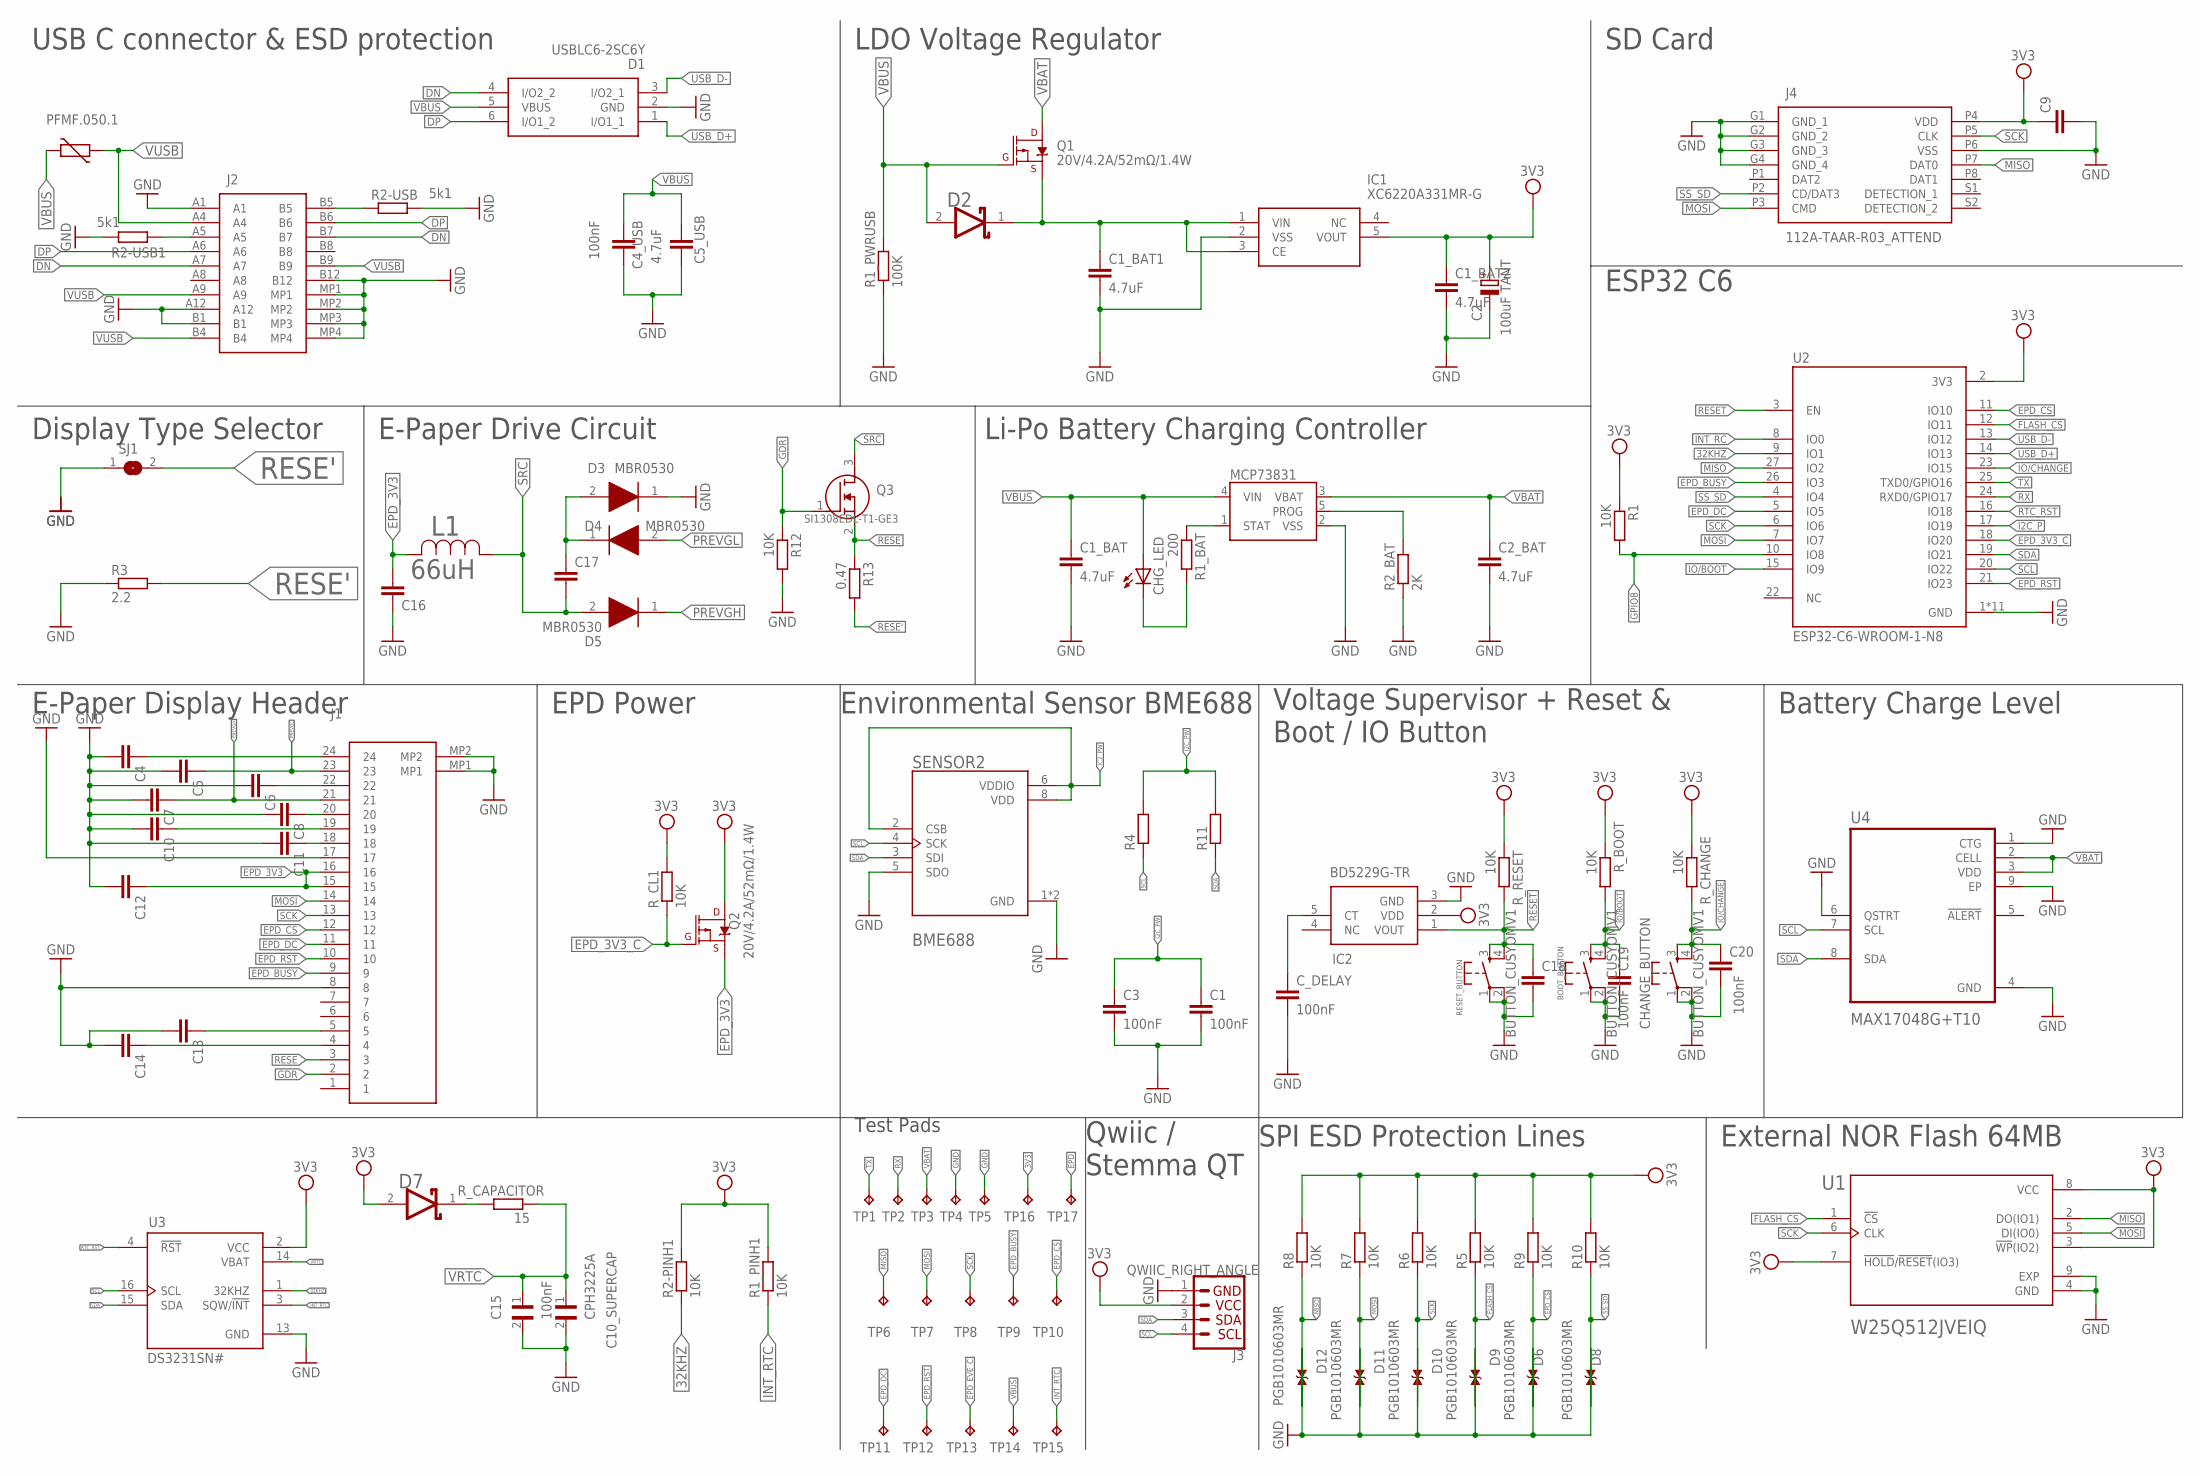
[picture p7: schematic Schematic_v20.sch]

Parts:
BOOT_BUTTON: BUTTON_CUSYOMV1; MYBUTTON
C1, C3, C4_USB, C19, C20: 100nF; ESP32_WROVER_EAGLE-LTSPICE_C0402
C1_BAT, C1_BAT1, C1_BAT2, C2_BAT, C5_USB: 4.7uF; ESP32_WROVER_EAGLE-LTSPICE_C0402
C2: 100uF TANT; RCL_CT3528
C4, C5, C6, C7, C8, C9, C10, C11, C12, C13, C14, C16, C17, C18: ESP32_WROVER_EAGLE-LTSPICE_CC0402; ESP32_WROVER_EAGLE-LTSPICE_C0402
C10_SUPERCAP: CPH3225A; CAPCP3225X100N
C15: 100nF; CAPCP3225X100N
CHANGE_BUTTON: BUTTON_CUSYOMV1; MYBUTTON
CHG_LED: ADAFRUIT_LEDCHIP-LED0603; ADAFRUIT_CHIP-LED0603
C_DELAY: 100nF; ESP32_WROVER_EAGLE-LTSPICE_C0402
D1: USBLC6-2SC6Y; SOT95P280X145-6N
D2: SD0805S020S1R0; ESP32_WROVER_AVX---SD0805S020S1R0_AVX_SD0805S020S1R0_0
D3, D4, D5: MBR0530; SOD3716X135N
D6, D8, D9, D10, D11, D12: PGB1010603MR; DIOC1608X36N
D7: ESP32_WROVER_AVX---SD0805S020S1R0_AVX_SD0805S020S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; ESP32_WROVER_AVX---SD0805S020S1R0_AVX_SD0805S020S1R0_0
IC1: XC6220A331MR-G; SOT95P280X120-5N
IC2: BD5229G-TR; SOT95P280X125-5N
J1: FH34SRJ-24S-0.5SH_99_; FH34SRJ24S05SH99
J2: SAMACSYS_PARTS_USB4110-GF-A; SAMACSYS_PARTS_USB4110GFA
J3: QWIIC_RIGHT_ANGLE; JST04_1MM_RA
J4: 112A-TAAR-R03_ATTEND; 112ATAARR03ATTEND
L1: 66uH; IND_4828-WE-TPC_WRE
MCP73831: ESP32_WROVER_SPARKFUN-IC-POWER_MCP73831; ESP32_WROVER_SPARKFUN-IC-POWER_SOT23-5
Q1, Q2: 20V/4.2A/52mΩ/1.4W; ESP32_WROVER_SPARKFUN-DISCRETESEMI_SOT23-3
Q3: SI1308EDL-T1-GE3; SOT65P210X110-3N
R1, R1_PINH1, R2-PINH1, R5, R6, R7, R8, R9, R10, R12: 10K; ESP32_WROVER_EAGLE-LTSPICE_R0402
R1_BAT: 200; ESP32_WROVER_EAGLE-LTSPICE_R0402
R1_PWRUSB: 100K; ESP32_WROVER_EAGLE-LTSPICE_R0402
R2: PFMF.050.1; ESP32C6_VARISTOR_CT/CN1812
R2-USB, R2-USB1: 5k1; ESP32_WROVER_EAGLE-LTSPICE_R0402
R2_BAT: 2K; ESP32_WROVER_EAGLE-LTSPICE_R0402
R3: 2.2; ESP32_WROVER_EAGLE-LTSPICE_R0402
R4, R11: ESP32_WROVER_EAGLE-LTSPICE_RR0402; ESP32_WROVER_EAGLE-LTSPICE_R0402
R13: 0.47; ESP32_WROVER_EAGLE-LTSPICE_R0402
RESET_BUTTON: BUTTON_CUSYOMV1; MYBUTTON
R_BOOT: 10K; ESP32_WROVER_EAGLE-LTSPICE_R0402
R_CAPACITOR: 15; ESP32_WROVER_EAGLE-LTSPICE_R0402
R_CHANGE: 10K; ESP32_WROVER_EAGLE-LTSPICE_R0402
R_CL1: 10K; ESP32_WROVER_EAGLE-LTSPICE_R0402
R_RESET: 10K; ESP32_WROVER_EAGLE-LTSPICE_R0402
SENSOR2: BME688; ESP32_WROVER_BME680_PSON80P300X300X100-8N
SJ1: SJ
TP1, TP2, TP3, TP4, TP5, TP6, TP7, TP8, TP9, TP10, TP11, TP12, TP13, TP14, TP15, TP16, TP17: TPTP20R; TP20R
U1: W25Q512JVEIQ; SON127P600X800X80-9N
U2: ESP32-C6-WROOM-1-N8; XCVR_ESP32-C6-WROOM-1-N8
U3: DS3231SN#; SOIC127P1032X265-16N
U4: MAX17048G+T10; SON50P200X200X80-9N

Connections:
3V3: C1_BAT2.1, C2.+, C9.1, D7.2 (ANODE), IC1.5 (VOUT), IC2.2 (VDD), J3.2, J4.P4 (VDD), Q2.3 (D), R1.1, R1_PINH1.2, R2-PINH1.2, R5.2, R6.2, R7.2, R8.2, R9.2, R10.2, R_BOOT.1, R_CHANGE.1, R_CL1.2, R_RESET.1, TP16.TP, U1.3 (!WP!(IO2)), U1.7 (!HOLD!/!RESET!(IO3)), U1.8 (VCC), U2.2 (3V3), U3.2 (VCC)
32KHZ: R2-PINH1.1, U2.9 (IO1), U3.1 (32KHZ)
DN: D1.4 (I/O2_2), J2.A7, J2.B7
DP: D1.6 (I/O1_2), J2.A6, J2.B6
EPD: TP17.TP
EPD_3V3: C12.1, C16.1, J1.15, J1.16, L1.2, Q2.2 (S)
EPD_3V3_C: Q2.1 (G), R_CL1.1, U2.18 (IO20)
EPD_BUSY: J1.9, TP9.TP, U2.26 (IO3)
EPD_CS: D6.2, J1.12, R9.1, TP10.TP, U2.11 (IO10)
EPD_DC: J1.11, TP11.TP, U2.5 (IO5)
EPD_EVE_C: TP13.TP
EPD_RST: J1.10, TP12.TP, U2.21 (IO23)
FLASH_CS: D9.2, R5.1, U1.1 (!CS), U2.12 (IO11)
GDR: J1.2, Q3.1 (G), R12.1
GND: BOOT_BUTTON.1, BOOT_BUTTON.2, C1.2, C1_BAT.2, C1_BAT1.2, C1_BAT2.2, C2.-, C2_BAT.2, C3.2, C4.2, C4_USB.2, C5.2, C5_USB.2, C6.2, C7.2, C8.2, C9.2, C10.2, C10_SUPERCAP.2, C11.2, C12.2, C13.2, C14.2, C15.2, C16.2, C18.2, C19.2, C20.2, CHANGE_BUTTON.1, CHANGE_BUTTON.2, C_DELAY.2, D1.2 (GND), D4.1 (K), D6.1, D8.1, D9.1, D10.1, D11.1, D12.1, IC1.2 (VSS), IC2.3 (GND), J1.8, J1.17, J1.MP1, J1.MP2, J2.A1, J2.A12, J2.B1, J2.B12, J2.MP1, J2.MP2, J2.MP3, J2.MP4, J3.1, J4.G1 (GND_1), J4.G2 (GND_2), J4.G3 (GND_3), J4.G4 (GND_4), J4.P6 (VSS), MCP73831.2 (VSS), R1_PWRUSB.1, R2-USB.2, R2-USB1.1, R2_BAT.1, R3.1, R12.2, RESET_BUTTON.1, RESET_BUTTON.2, SENSOR2.1 (GND), SENSOR2.5 (SDO), SENSOR2.7 (GND), SJ1.1, TP4.TP, TP5.TP, U1.4 (GND), U1.9 (EXP), U2.1 (GND), U2.28 (GND), U2.29_1 (GND), U2.29_2 (GND), U2.29_3 (GND), U2.29_4 (GND), U2.29_5 (GND), U2.29_6 (GND), U2.29_7 (GND), U2.29_8 (GND), U2.29_9 (GND), U3.13 (GND), U4.1 (CTG), U4.4 (GND), U4.6 (QSTRT), U4.9 (EP)
GPIO8: R1.2, U2.10 (IO8)
I2C_P: U2.17 (IO19)
I2C_PW: C1.1, C3.1, R4.2, R11.2
IC2_PW: SENSOR2.2 (CSB), SENSOR2.6 (VDDIO), SENSOR2.8 (VDD)
INT_RC: U2.8 (IO0)
INT_RTC: R1_PINH1.1, TP15.TP, U3.3 (SQW/!INT)
IO/BOOT: BOOT_BUTTON.3, BOOT_BUTTON.4, C19.1, R_BOOT.2, U2.15 (IO9)
IO/CHANGE: C20.1, CHANGE_BUTTON.3, CHANGE_BUTTON.4, R_CHANGE.2, U2.23 (IO15)
MISO: D12.2, J4.P7 (DAT0), R8.1, TP6.TP, U1.2 (DO(IO1)), U2.27 (IO2)
MOSI: D11.2, J1.14, J4.P3 (CMD), R7.1, TP7.TP, U1.5 (DI(IO0)), U2.7 (IO7)
unnamed: J2.A5, R2-USB1.2
unnamed: C4.1, J1.24
unnamed: C1_BAT1.1, D2.1 (CATHODE), IC1.1 (VIN), IC1.3 (CE), Q1.2 (S)
unnamed: CHG_LED.C, R1_BAT.2
unnamed: MCP73831.5 (PROG), R2_BAT.2
unnamed: J2.B5, R2-USB.1
unnamed: MCP73831.1 (STAT), R1_BAT.1
unnamed: D7.1 (CATHODE), R_CAPACITOR.2
unnamed: C6.1, J1.22
unnamed: C_DELAY.1, IC2.5 (CT)
unnamed: C8.1, J1.20
unnamed: C10.1, J1.19
unnamed: C11.1, J1.18
unnamed: C17.1, D3.1 (K), D4.2 (A)
unnamed: C13.1, J1.5
unnamed: C14.1, J1.4
PREVGH: C7.1, D5.1 (K), J1.21
PREVGL: C5.1, D3.2 (A), J1.23
RESE: J1.3, Q3.2 (S), R13.1
RESE': R3.2, R13.2, SJ1.2
RESET: C18.1, IC2.1 (VOUT), RESET_BUTTON.3, RESET_BUTTON.4, R_RESET.2, U2.3 (EN)
RTC_RST: U2.16 (IO18), U3.4 (!RST)
RX: TP2.TP, U2.24 (RXD0/GPIO17)
SCK: D10.2, J1.13, J4.P5 (CLK), R6.1, TP8.TP, U1.6 (CLK), U2.6 (IO6)
SCL: J3.4, R4.1, SENSOR2.4 (SCK), U2.20 (IO22), U3.16 (SCL), U4.7 (SCL)
SDA: J3.3, R11.1, SENSOR2.3 (SDI), U2.19 (IO21), U3.15 (SDA), U4.8 (SDA)
SRC: C17.2, D5.2 (A), L1.1, Q3.3 (D)
SS_SD: D8.2, J4.P2 (CD/DAT3), R10.1, U2.4 (IO4)
TX: TP1.TP, U2.25 (TXD0/GPIO16)
USB_D+: D1.1 (I/O1_1), U2.14 (IO13)
USB_D-: D1.3 (I/O2_1), U2.13 (IO12)
VBAT: C2_BAT.1, MCP73831.3 (VBAT), Q1.3 (D), TP3.TP, U4.2 (CELL), U4.3 (VDD)
VBUS: C1_BAT.1, C4_USB.1, C5_USB.1, CHG_LED.A, D1.5 (VBUS), D2.2 (ANODE), MCP73831.4 (VIN), Q1.1 (G), R1_PWRUSB.2, R2.1, TP14.TP
VRTC: C10_SUPERCAP.1, C15.1, R_CAPACITOR.1, U3.14 (VBAT)
VUSB: J2.A4, J2.A9, J2.B4, J2.B9, R2.2

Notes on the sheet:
USB C connector & ESD protection
SD Card
ESP32 C6
Battery Charge Level
External NOR Flash 64MB
SPI ESD Protection Lines
Qwiic / Stemma QT
Test Pads
LDO Voltage Regulator
Display Type Selector
Li-Po Battery Charging Controller
Environmental Sensor BME688
E-Paper Display Header
EPD Power
E-Paper Drive Circuit
Voltage Supervisor + Reset & Boot / IO Button

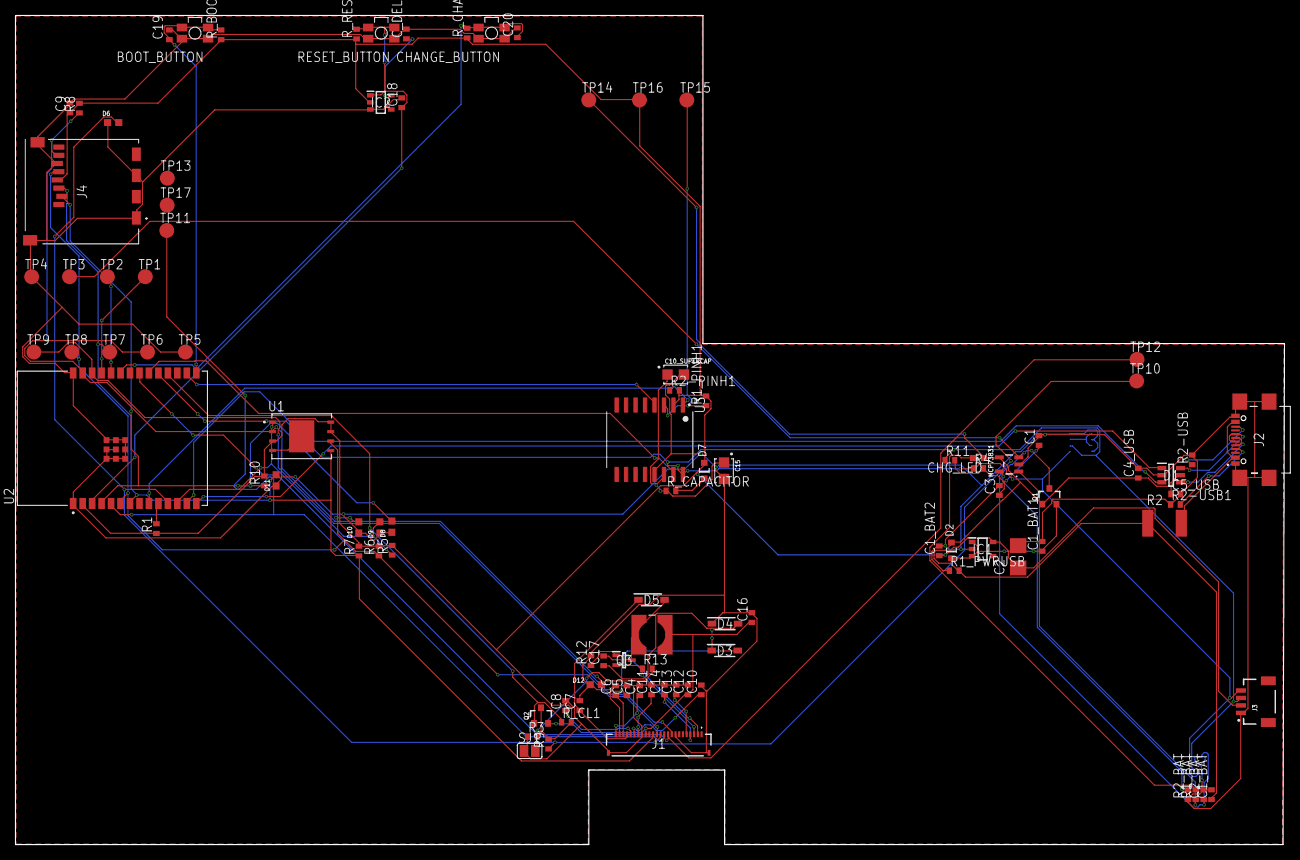
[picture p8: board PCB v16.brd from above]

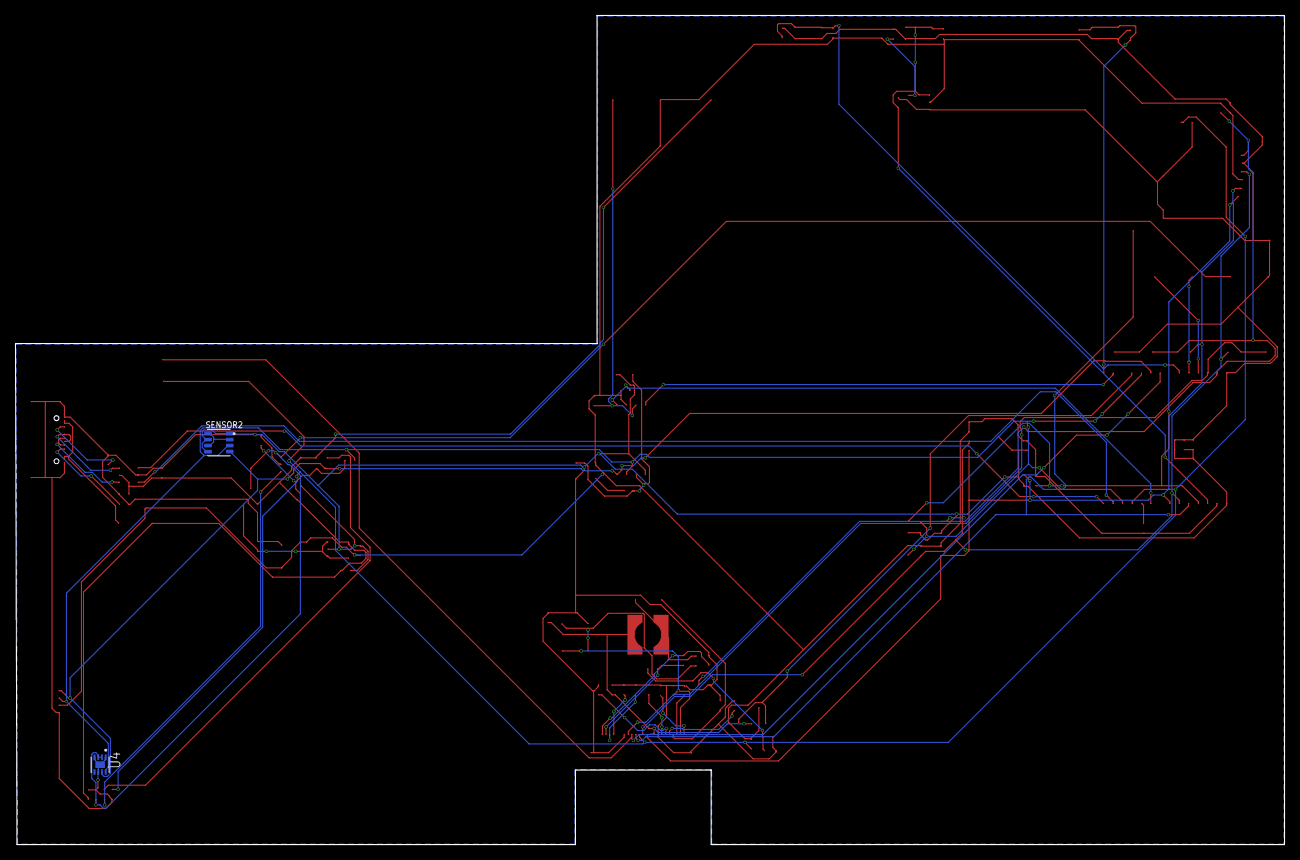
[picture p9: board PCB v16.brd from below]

Board: 2 copper layers, 170.2 x 111.2 mm, 103 parts (2 on the bottom side), 56 nets.

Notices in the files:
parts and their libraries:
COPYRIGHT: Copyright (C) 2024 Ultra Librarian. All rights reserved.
